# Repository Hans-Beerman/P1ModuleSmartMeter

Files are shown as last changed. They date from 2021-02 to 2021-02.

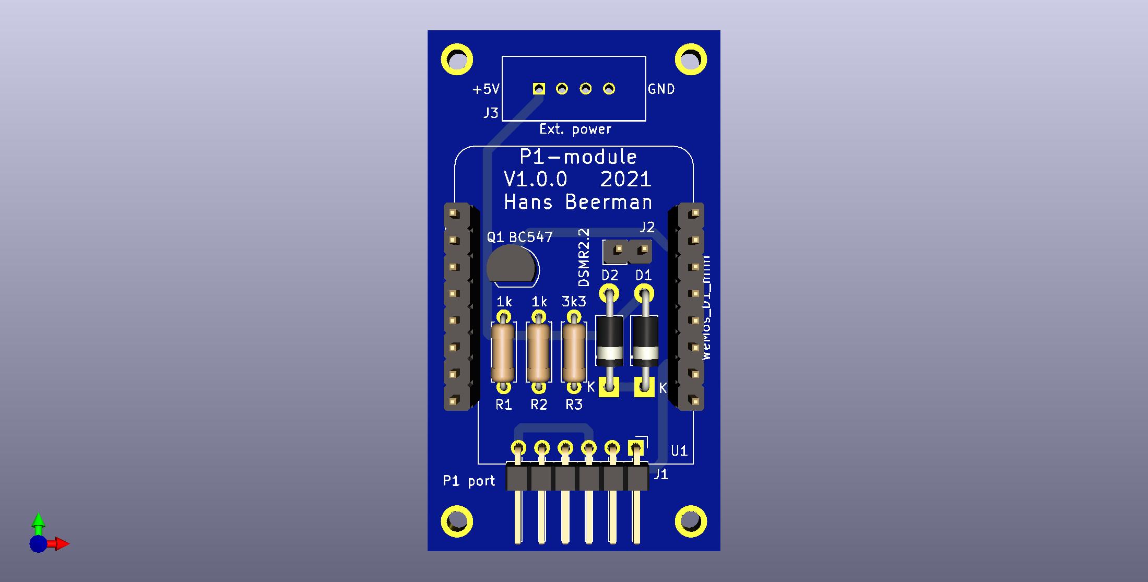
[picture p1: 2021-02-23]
KiCad_Files/WemosSmartMeter/P1-module V1.0.0.jpg

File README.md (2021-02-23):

**P1-module smart meter**

The P1-module is a small module, based on a Wemos D1 Mini (with an ESP8266) to collect information from the P1 port of a (Dutch) smart meter.

This module can be used for smart meters running DSMR Version 2.2 or higher.

For smart meters with DSMR V2.2 a jumper must be placed and the PCB must be powered by a 5V USB power supply. For more information, see the README.md in the KiCad directory of this repository

**Software for the P1-module**

The information collected from the smart meter is sent to a mqtt server of your own choice. The details about this server must be set in the .passwd.h file in the include directory of the PlatformIO project. This file must be added by yourself and should contain the following:

_/\* \*\*\*\*\*\*\*\*\*\*\*\*\*\*\*\*\*\*\*\*\*\*\*\*\*\*\*\*\*\*\*\*\*\*\*\*\*\*\*\*\*\*\*\*\*\*\*\*\*\*\*\*\*\*\*\*\*\*\*\*\*\*\*\*\*\*\*\*\*\*\*_

_PLEASE READ THIS FIRST_

_Add a file to the include directory of this project with the_

_following name:_

_.passwd.h_

_The content of this file should be:_

_#pragma once_

_// WiFi credentials_

_#define WIFI\_NETWORK &quot;YOUR\_WIFI\_NETWORK\_NAME&quot;_

_#define WIFI\_PASSWD &quot;YOUR\_WIFI\_NETWORK\_PASSWORD&quot;_

_#define FALLBACK\_WIFI\_NETWORK &quot;Dummy&quot; // or chose any other name you like_

_#define FALLBACK\_WIFI\_PASSWD &quot;12345678&quot; // or take another password_

_// mqtt server_

_#define MY\_MQTT\_HOST &quot;your\_mqtt\_host e.g. 10.10.10.10&quot;_

_#define MY\_MQTT\_PORT &quot;1883&quot;_

_#define MY\_MQTT\_USERNAME &quot;your\_mqtt\_server\_username&quot;_

_#define MY\_MQTT\_PASSWORD &quot;your\_mqtt\_server.password&quot;_

_// OTA credentials_

_#define OTA\_PASSWORD &quot;MyPassW00rd&quot; // must be the same in platformio.ini_

_Also check in the platformio.ini file the upload\_port set._

_In the current file this port is set for a serial connection to a_

_Linux Ubuntu PC for a Windows PC running Visual Studio Code with_

_PlatformIO you should use something like:_

_upload\_port = COM3_

_Or any other comport number which is used for the serial connection_

_For further information see the README.md in the repository on GitHub_

_\*\*\*\*\*\*\*\*\*\*\*\*\*\*\*\*\*\*\*\*\*\*\*\*\*\*\*\*\*\*\*\*\*\*\*\*\*\*\*\*\*\*\*\*\*\*\*\*\*\*\*\*\*\*\*\*\*\*\*\*\*\*\*\*\*\*\*\*\*\*\* \*/_

**WiFi network settings**

Default the P1-module uses the WiFi credentials as set in the .passw.h file, because in main.cpp the following #define is set:

_#define USE\_DEFAULT\_WIFI\_SETTINGS true_

If this #define is set to false:

_#define USE\_DEFAULT\_WIFI\_SETTINGS false_

In that case, if the P1-module is not able to connect to a WiFi network, the P1-module will set up a WiFi Access Point (AP) with the FALLBACK WiFi credentials as set in the .passwd.h file. Also a webserver (with IP address: 192.168.4.1) will be started.

If you connect, e.g. with a phone, a tablet or a PC to this AP, you will be able to select and configure a WiFi network and the mqtt server information, with the help of a web browser. The information set will be stored in eeprom.

**Overview of repository**

This repository has the following subdirs:

- **KiCad\_files:**

The design of the PCB used for the Node/Controller.

- **PlatformIO\_Files:**

The source code for the P1-module. For the development of this software PlatformIO is used, an Extension on Visual Studio Code.

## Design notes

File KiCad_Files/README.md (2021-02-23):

**P1-port smart meter module**

The following components are only needed if the smart meter uses DSMR version 2.2. For higher versions these components are not needed:

J3 USB connector

D1 Shottky diode

D2 Shottky diode, this diode must be replaced by a straight wire for higher DSMR versions.

J2 Jumper

In DSMR2.2 the USB connector is used to provide 5V, to be delivered by a 5V USB Power supply

For DSMR2.2 a jumper must be placed on J2, because the serial connection to the DSMR2.2 meter uses different settings. E.g. a baudrate of 9600 baud in DSMR2.2, while in highet DSMR versions the baudrate is 115200 baud.

**List of components used:**

J1 Header + cable with RJ12 connector, RJ12 naar 6 Pins Dupont-Jumper Adapter - P1 Kabel Compatible {e.g. [https://www.tinytronics.nl/shop/nl/kabels/adapters/rj12-naar-6-pins-dupont-jumper-adapter](https://www.tinytronics.nl/shop/nl/kabels/adapters/rj12-naar-6-pins-dupont-jumper-adapter))

J2 2-pole header (e.g. [https://www.tinytronics.nl/shop/nl/connectoren/pin-header/40-pins-header-male](https://www.tinytronics.nl/shop/nl/connectoren/pin-header/40-pins-header-male))

J3 USB-aansluitstekker printmontage Stekker, recht Typ A USB-stekker type A 774842 TRU COMPONENTS (e.g. [https://www.conrad.nl/p/usb-aansluitstekker-printmontage-stekker-recht-typ-a-usb-stekker-type-a-774842-tru-components-inhoud-1-stuks-1567162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](https://www.conrad.nl/p/usb-aansluitstekker-printmontage-stekker-recht-typ-a-usb-stekker-type-a-774842-tru-components-inhoud-1-stuks-1567162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))

U1 WeMos D1 Mini, Wemos D1 Mini V3 - ESP8266 - CH340 (e.g. [https://www.tinytronics.nl/shop/nl/arduino/wemos/wemos-d1-mini-v2-esp8266-12f-ch340](https://www.tinytronics.nl/shop/nl/arduino/wemos/wemos-d1-mini-v2-esp8266-12f-ch340))

Q1 BC546 (e.g. [https://www.tinytronics.nl/shop/nl/componenten/transistor-fet/npn-transistor-bc547](https://www.tinytronics.nl/shop/nl/componenten/transistor-fet/npn-transistor-bc547))

D1, D2 1N5819 (e.g. [https://www.conrad.nl/p/stmicroelectronics-skottky-diode-gelijkrichter-1n5819-do-41-40-v-enkelvoudig-155460](https://www.conrad.nl/p/stmicroelectronics-skottky-diode-gelijkrichter-1n5819-do-41-40-v-enkelvoudig-155460))

R1, R2 Resistor 1k (e.g. [https://www.conrad.nl/p/yageo-mf0207fte52-1k-metaalfilmweerstand-1-k-axiaal-bedraad-0207-06-w-1-1-stuks-1417606](https://www.conrad.nl/p/yageo-mf0207fte52-1k-metaalfilmweerstand-1-k-axiaal-bedraad-0207-06-w-1-1-stuks-1417606))

R3 Resistor 3k3 (e.g. [https://www.conrad.nl/p/yageo-mf0207fte52-3k3-metaalfilmweerstand-33-k-axiaal-bedraad-0207-06-w-1-1-stuks-1417733](https://www.conrad.nl/p/yageo-mf0207fte52-3k3-metaalfilmweerstand-33-k-axiaal-bedraad-0207-06-w-1-1-stuks-1417733))

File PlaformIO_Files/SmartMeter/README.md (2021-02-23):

**SlimmeMeter**

SlimmeMeter, de sourcecode voor een module om de slimme meter uit te lezen.

Voor het processorbordje waar deze sourcecode op draait wordt gebruik gemaakt van een Wemos D1 mini, die voorzien is van een ESP8266 processor, de robotdyn-d1-mini-pro-esp8266-4mb-cp2104

Zie bijvoorbeeld: https://www.tinytronics.nl/shop/nl/arduino/wemos/robotdyn-d1-mini-pro-esp8266-4mb-cp2104

De overige hardware is gemonteerd op een proefprintje: RobotDyn ProtoBoard Shield voor D1 Mini

Zie bijvoorbeeld: https://www.tinytronics.nl/shop/nl/arduino/wemos/robotdyn-protoboard-shield-voor-d1-mini

- **PlatformIO\_Files:**

Bevat de source code voor deze module. Voor het ontwikkelen van de software is gebruik gemaakt van PlatformIO, een extensie op Windowd Visual Studio Code. Deze subdirectory bevat alle PlatformIO project files.

Open de rootdirectory van dit project m.b.v. PlatformIO

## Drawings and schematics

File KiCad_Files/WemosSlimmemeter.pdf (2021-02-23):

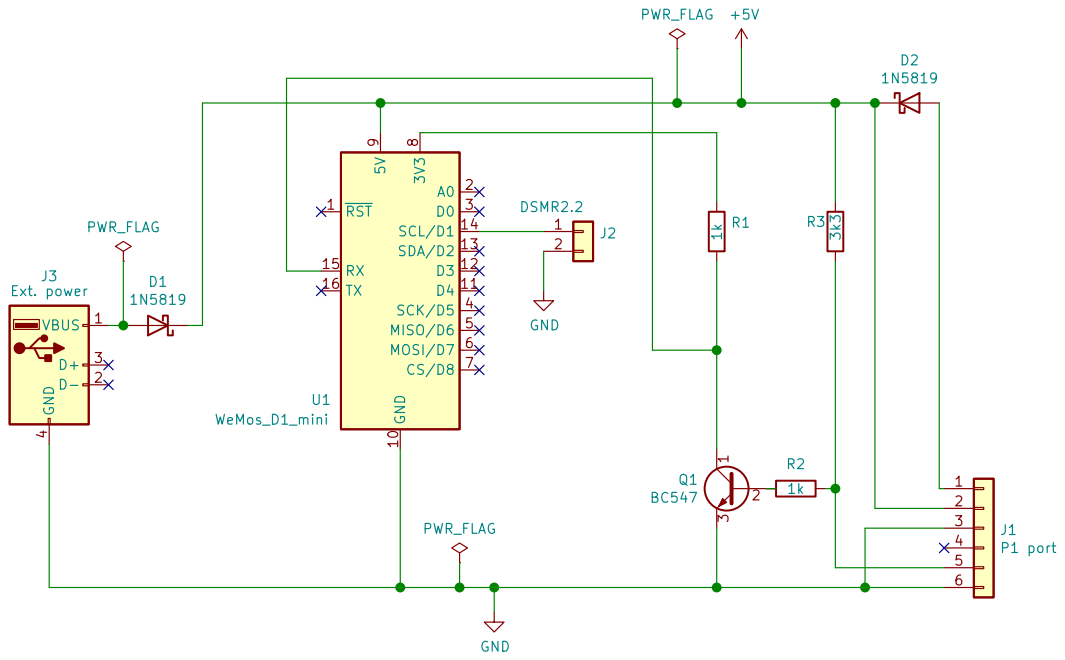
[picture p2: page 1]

Id: 1/1 Title: P1-port smart meter File: WemosSlimmemeter.sch Sheet: / SDS project Getekend door: Hans Beerman

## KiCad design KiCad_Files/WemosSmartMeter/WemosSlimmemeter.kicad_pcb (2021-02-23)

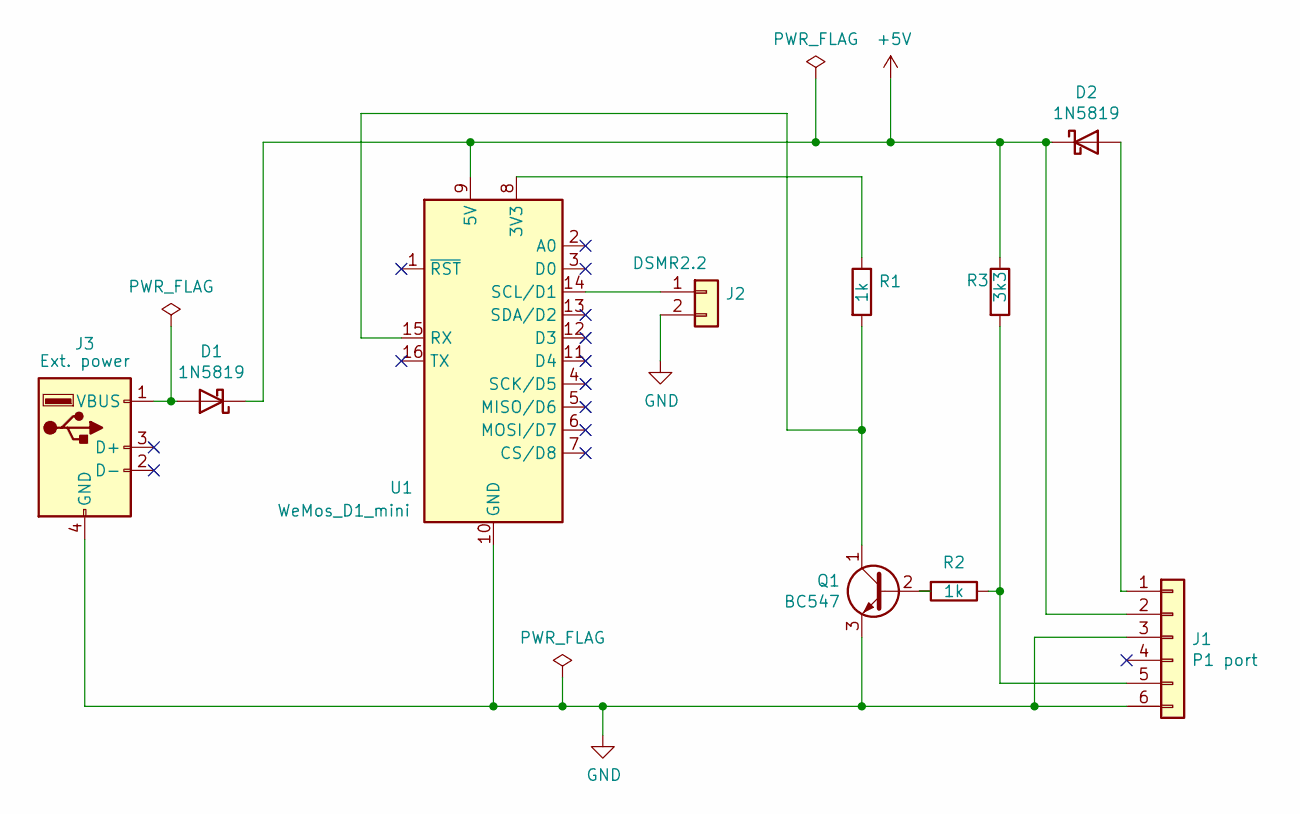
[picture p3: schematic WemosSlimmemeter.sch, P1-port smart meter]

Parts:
D1, D2: 1N5819; D_DO-41_SOD81_P10.16mm_Horizontal
J1: P1 port; PinHeader_1x06_P2.54mm_Horizontal
J2: DSMR2.2; PinHeader_1x02_P2.54mm_Vertical
J3: Ext. power; USB_A_Vertical
Q1: BC547; TO-92_Inline
R1, R2: 1k; R_Axial_DIN0207_L6.3mm_D2.5mm_P7.62mm_Horizontal
R3: 3k3; R_Axial_DIN0207_L6.3mm_D2.5mm_P7.62mm_Horizontal
U1: WeMos_D1_mini; WEMOS_D1_mini_light

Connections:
+5V: D1.1 (K), D2.1 (K), J1.2, R3.1, U1.9 (5V)
GND: J1.3, J1.6, J2.2, J3.4 (GND), Q1.3 (E), U1.10 (GND)
unnamed: D1.2 (A), J3.1 (VBUS)
unnamed: D2.2 (A), J1.1
unnamed: J1.5, R2.1, R3.2
unnamed: J2.1, U1.14 (SCL/D1)
unnamed: Q1.1 (C), R1.2, U1.15 (RX)
unnamed: Q1.2 (B), R2.2
unnamed: R1.1, U1.8 (3V3)

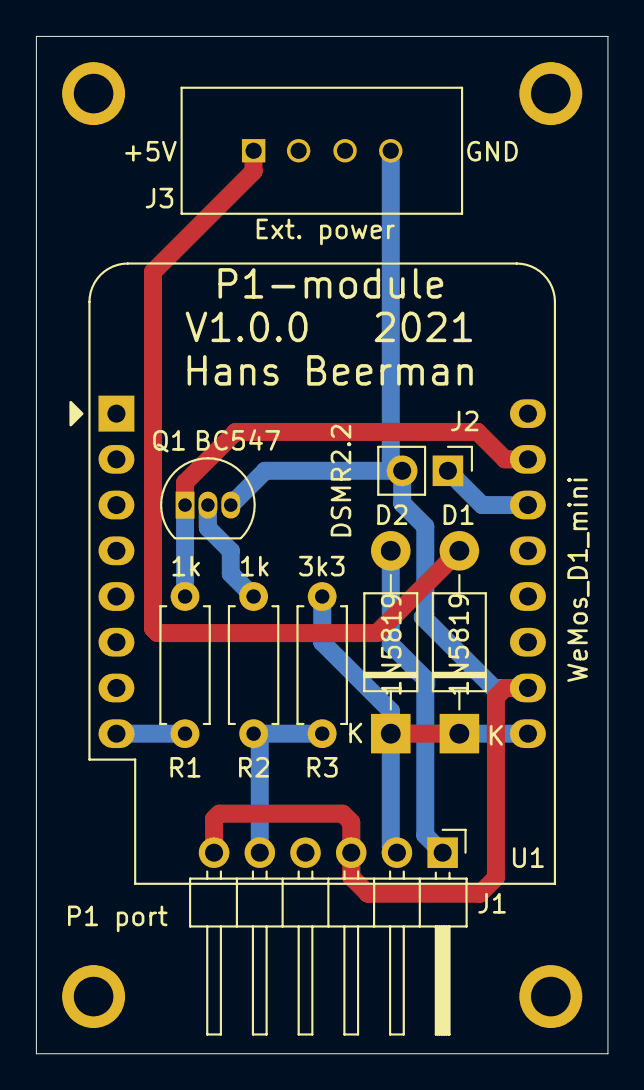
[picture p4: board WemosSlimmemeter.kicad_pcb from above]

Board: 2 copper layers, 31.8 x 56.5 mm, 10 parts (0 on the bottom side), 9 nets.

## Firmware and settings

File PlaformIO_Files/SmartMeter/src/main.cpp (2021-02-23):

#include <Arduino.h>
#include <FS.h>
#include <EEPROM.h>
#include <DNSServer.h>
#include <ESP8266WiFi.h>
#include <Ticker.h>
#include <WiFiManager.h>
#include "ESPTelnet.h" 
#include <ESP8266mDNS.h>
#include <ArduinoOTA.h>
#include <PubSubClient.h>
#include <WiFiUdp.h>
#include <NTP.h> // install NTP by Stefan Staub
//
// information about NTP.h, see: https://platformio.org/lib/show/5438/NTP
//
/*

/* ***********************************************************************
PLEASE READ THIS FIRST

Add a file to the include directory of this project with the 
following name:

.passwd.h

The content of this file should be:

#pragma once

// WiFi credentials
#define WIFI_NETWORK "YOUR_WIFI_NETWORK_NAME"
#define WIFI_PASSWD "YOUR_WIFI_NETWORK_PASSWORD"

#define FALLBACK_WIFI_NETWORK "Dummy"  // or chose any other name you like
#define FALLBACK_WIFI_PASSWD "12345678" // or take another password

// mqtt server
#define MY_MQTT_HOST "your_mqtt_host e.g. 10.10.10.10"
#define MY_MQTT_PORT "1883"
#define MY_MQTT_USERNAME "your_mqtt_server_username"
#define MY_MQTT_PASSWORD "your_mqtt_server.password"

// OTA credentials
#define OTA_PASSWORD "MyPassW00rd" // must be the same in platformio.ini

Also check in the platformio.ini file the upload_port set.

In the current file this port is set for a serial connection to a

Linux Ubuntu PC for a Windows PC running Visual Studio Code with
PlatformIO you should use something like:
upload_port = COM3
Or any other comport number which is used for the serial connection

For further information see the README.md in the repository on GitHub

*********************************************************************** */

// * Include settings
#include ".passwd.h"
#include "settingsMain.h"

// * include EEProm functions
#include "MyEEprom.h"
#define MODULE_NAME "P1PortModule"

#define USE_DEFAULT_WIFI_SETTINGS true

// * Initiate led blinker library
Ticker ticker;

// * Initiate WIFI client
WiFiClient espClient;

// WiFiClient espClient;
PubSubClient mqtt_client(espClient);

// * Initiate telnet server
ESPTelnet telnet;

// * IP address module
IPAddress ip_addr;

// * for NTP
#define NTP_UPDATE_WINDOW (1000 * 60 * 60) // in ms = 1 hour

unsigned long lastNTPUpdateTime = 0;

WiFiUDP wifiUDP;

char topic[255];
char logMess[255];
bool firstStart = true;
unsigned long measureStartTime = 0;

// To test DSMRV2.2 functionality on > DSMRV2.2 smart meter, uncomment below statement
//#define TEST_DSMRV2_2

// In case DSMR V2.2 is used
bool DSMRV2_2IsUsed = false;

bool timeStampReceived = false;

// **********************************
// * Function definitions           *
// **********************************


// **********************************
// * Ticker (System LED Blinker)    *
// **********************************

// * Blink on-board Led
void tick()
{
    // * Toggle state
    int state = digitalRead(LED_BUILTIN);    // * Get the current state of GPIO1 pin
    digitalWrite(LED_BUILTIN, !state);       // * Set pin to the opposite state
}

// **********************************
// * NTP                            *
// **********************************

NTP ntp(wifiUDP);

char ntpDateTimeStr[64];
char newDateTimeStr[64];
unsigned long NTPUpdatedTime = 0;
int currentHour;
int currentMinutes;
int currentSecs;
int currentDay;
int currentMonth;
int currentYear;

void initNTP() {
  ntp.ruleDST("CEST", Last, Sun, Mar, 2, 120); // last sunday in march 2:00, timezone +120min (+1 GMT + 1h summertime offset)
  ntp.ruleSTD("CET", Last, Sun, Oct, 3, 60); // last sunday in october 3:00, timezone +60min (+1 GMT)
  ntp.begin(false); // start NTP nonblocking
  ntp.update();

  currentHour = ntp.hours();
  currentMinutes = ntp.minutes();
  currentSecs = ntp.seconds();
  currentDay = ntp.day();
  currentMonth = ntp.month();
  currentYear = ntp.year();

  snprintf(ntpDateTimeStr, sizeof(ntpDateTimeStr), "Last boot: %4d-%02d-%02d %02d:%02d:%02d", currentYear, currentMonth, currentDay, currentHour, currentMinutes, currentSecs);

  ntp.updateInterval(NTP_UPDATE_WINDOW);
  ntp.update();
}

void getCurrentNTPTime() {
  currentHour = ntp.hours();
  currentMinutes = ntp.minutes();
  currentSecs = ntp.seconds();
  currentDay = ntp.day();
  currentMonth = ntp.month();
  currentYear = ntp.year();

  snprintf(newDateTimeStr, sizeof(newDateTimeStr), "%4d-%02d-%02d %02d:%02d:%02d", currentYear, currentMonth, currentDay, currentHour, currentMinutes, currentSecs);
}




// **********************************
// * telnet                           *
// **********************************

// Callback functions for telnet server
void onTelnetConnect(String ip) {
    Serial.print("- Telnet: ");
    Serial.print(telnet.getIP());
    Serial.println(" connected");
    telnet.println("\n\rWelcome " + telnet.getIP() + "\r");
    telnet.println("(Use ^] + q  to disconnect.)\r");
    telnet.println("\r");
    telnet.print(P1_MODULE_SOFTWARE_VERSION);
    telnet.println("\r");
    telnet.print(DATE_OFF_VERSION);
    telnet.println("\r");
    telnet.println("\r");
    telnet.println(ntpDateTimeStr);
    telnet.println("\r");
}

void onTelnetDisconnect(String ip) {
    Serial.print("- Telnet: ");
    Serial.print(ip);
    Serial.println(" disconnected");
}
void onTelnetReconnect(String ip) {
    Serial.print("- Telnet: ");
    Serial.print(ip);
    Serial.println(" reconnected");
}

void onTelnetConnectionAttempt(String ip) {
    Serial.print("- Telnet: ");
    Serial.print(telnet.getLastAttemptIP());
    Serial.println(" tried to connected");
}


void setupTelnet() {
    if (telnet.begin()) {
        telnet.onConnect(onTelnetConnect);
        telnet.onConnectionAttempt(onTelnetConnectionAttempt);
        telnet.onReconnect(onTelnetReconnect);
        telnet.onDisconnect(onTelnetDisconnect);
        Serial.println("- Telnet is running. Connect to Telnet using:");
        Serial.println("telnet " + ip_addr.toString());
    } else {
    // could not create server
        Serial.println("- Failed to create Telnet server. Is device connected to WiFi?");
        delay(10000);
        ESP.reset();
        delay(1000); 
    }
}

// **********************************
// * MQTT                           *
// **********************************

// * Send a message to a broker topic
void send_mqtt_message(const char *topic, char *payload)
{
    Serial.printf("MQTT Outgoing on %s: ", topic);
    Serial.println(payload);

    bool result = mqtt_client.publish(topic, payload, false);

    if (!result)
    {
        Serial.printf("MQTT publish to topic %s failed\n", topic);
    }
}

// * Reconnect to MQTT server and subscribe to in and out topics
bool mqtt_reconnect()
{
    // * Loop until we're reconnected
    int MQTT_RECONNECT_RETRIES = 0;

    while (!mqtt_client.connected() && MQTT_RECONNECT_RETRIES < MQTT_MAX_RECONNECT_TRIES)
    {
        MQTT_RECONNECT_RETRIES++;
        Serial.printf("MQTT connection attempt %d / %d ...\n", MQTT_RECONNECT_RETRIES, MQTT_MAX_RECONNECT_TRIES);
        snprintf(logMess, sizeof(logMess), "MQTT connection attempt %d / %d ...\n\r", MQTT_RECONNECT_RETRIES, MQTT_MAX_RECONNECT_TRIES);
        telnet.println(logMess);


        // * Attempt to connect
        if (mqtt_client.connect(HOSTNAME, MQTT_USER, MQTT_PASS))
        {
            Serial.println(F("MQTT connected!"));
            telnet.println(F("MQTT connected!\r"));

            // * Once connected, publish an announcement...
            snprintf(logMess, sizeof(logMess), "p1 port module alive, hostname: %s", HOSTNAME);
            mqtt_client.publish("Status", logMess);

            Serial.printf("MQTT root topic: %s\n", MQTT_ROOT_TOPIC);
            snprintf(logMess, sizeof(logMess), "MQTT root topic: %s\n\r", MQTT_ROOT_TOPIC);
            telnet.println(logMess);

        }
        else
        {
            Serial.print(F("MQTT Connection failed: rc="));
            Serial.println(mqtt_client.state());
            Serial.println(F(" Retrying in 2 seconds"));
            Serial.println("");
            snprintf(logMess, sizeof(logMess), "MQTT Connection failed: rc=%d\r", mqtt_client.state());
            telnet.println(logMess);
            telnet.println(F(" Retrying in 2 seconds\r"));
            telnet.println("\r");
            delay(2000);
        }
    }

    if (MQTT_RECONNECT_RETRIES >= MQTT_MAX_RECONNECT_TRIES)
    {
        Serial.printf("*** MQTT connection failed, giving up after %d tries ...\n", MQTT_RECONNECT_RETRIES);
        Serial.println(F(" Retrying in 10 seconds"));
        snprintf(logMess, sizeof(logMess), "*** MQTT connection failed, giving up after %d tries ...\n", MQTT_RECONNECT_RETRIES);
        telnet.println(logMess);
        telnet.println(F(" Retrying in 10 seconds\r"));
        return false;
    }

    return true;
}

void send_metric(const char * name, long metric)
{
    Serial.print(F("Sending metric to broker: "));
    Serial.print(name);
    Serial.print(F("="));
    Serial.println(metric);

    char output[22];
    ltoa(metric, output, 10);

    snprintf(topic, sizeof(topic), "%s/%s", MQTT_ROOT_TOPIC, name);
    send_mqtt_message(topic, output);
    yield();
}

void send_data_to_broker()
{
    send_metric("consumption_low_tarif", CONSUMPTION_LOW_TARIF);
    send_metric("consumption_high_tarif", CONSUMPTION_HIGH_TARIF);
    send_metric("delivery_low_tarif", DELIVERY_LOW_TARIF);
    send_metric("delivery_high_tarif", DELIVERY_HIGH_TARIF);
    send_metric("actual_consumption", ACTUAL_CONSUMPTION);
    send_metric("actual_delivery", ACTUAL_DELIVERY);
    send_metric("instant_power_usage", INSTANT_POWER_USAGE);
    send_metric("instant_power_current", INSTANT_POWER_CURRENT);
    send_metric("gas_meter_m3", GAS_METER_M3);

    send_metric("actual_tarif_group", ACTUAL_TARIF);
    send_metric("short_power_outages", SHORT_POWER_OUTAGES);
    send_metric("long_power_outages", LONG_POWER_OUTAGES);
    send_metric("short_power_drops", SHORT_POWER_DROPS);
    send_metric("short_power_peaks", SHORT_POWER_PEAKS);
}

// **********************************
// * P1                             *
// **********************************

unsigned int CRC16(unsigned int crc, unsigned char *buf, int len)
{
	for (int pos = 0; pos < len; pos++)
    {
		crc ^= (unsigned int)buf[pos];    // * XOR byte into least sig. byte of crc
                                          // * Loop over each bit
        for (int i = 8; i != 0; i--)
        {
            // * If the LSB is set
            if ((crc & 0x0001) != 0)
            {
                // * Shift right and XOR 0xA001
                crc >>= 1;
				crc ^= 0xA001;
			}
            // * Else LSB is not set
            else
                // * Just shift right
                crc >>= 1;
		}
	}
	return crc;
}

bool isNumber(char *res, int len)
{
    for (int i = 0; i < len; i++)
    {
        if (((res[i] < '0') || (res[i] > '9')) && (res[i] != '.' && res[i] != 0))
            return false;
    }
    return true;
}

int FindCharInArrayRev(char array[], char c, int len)
{
    for (int i = len - 1; i >= 0; i--)
    {
        if (array[i] == c)
            return i;
    }
    return -1;
}

long getValue(char *buffer, int maxlen, char startchar, char endchar)
{
    int s = FindCharInArrayRev(buffer, startchar, maxlen - 2);
    int l = FindCharInArrayRev(buffer, endchar, maxlen - 2) - s - 1;

    char res[16];
    memset(res, 0, sizeof(res));

    if (strncpy(res, buffer + s + 1, l))
    {
        if (endchar == '*')
        {
            if (isNumber(res, l))
                // * Lazy convert float to long
                return (1000 * atof(res));
        }
        else if (endchar == ')')
        {
            if (isNumber(res, l))
                return atof(res);
        }
    }
    return 0;
}

void getDateTimeP1(char *buffer, int maxlen, char startchar, char endchar)
{
    char tmpStr[10];
    int s = FindCharInArrayRev(buffer, startchar, maxlen);
    int l = FindCharInArrayRev(buffer, endchar, maxlen) - s - 1;
    
    memset(DATE_TIME_P1, 0, sizeof(DATE_TIME_P1));

    if (strncpy(DATE_TIME_P1, buffer + s + 1, l))
    {
        DATE_TIME_P1[l] = 0;
        if (l == 13) {
            tmpStr[0] = DATE_TIME_P1[6];
            tmpStr[1] = DATE_TIME_P1[7];
            tmpStr[2] = 0;
            P1_HOURS = atoi(tmpStr);
            tmpStr[0] = DATE_TIME_P1[8];
            tmpStr[1] = DATE_TIME_P1[9];
            tmpStr[2] = 0;
            P1_MINUTES = atoi(tmpStr);
        }
    } else {
        DATE_TIME_P1[0] = 0;
        P1_HOURS = -1;
        P1_MINUTES = -1;
    }
}

void getDateTimeNTP(void) {
    int year = ntp.year();
    int month = ntp.month();
    int day = ntp.day();
    int seconds = ntp.seconds();
    
    year = year - 2000;
    P1_HOURS = ntp.hours();
    P1_MINUTES = ntp.minutes();
    if (ntp.isDST() == 0) {
        snprintf(DATE_TIME_P1, sizeof(DATE_TIME_P1), "%02d%02d%02d%02d%02d%02d%c", year, month, day, P1_HOURS, P1_MINUTES, seconds, 'W');
    } else {
        snprintf(DATE_TIME_P1, sizeof(DATE_TIME_P1), "%02d%02d%02d%02d%02d%02d%c", year, month, day, P1_HOURS, P1_MINUTES, seconds, 'S');
    }
#ifdef TEST_DSMRV2_2    
    telnet.println(DATE_TIME_P1);
#endif    
}

bool decode_telegram(int len)
{
    int startChar = FindCharInArrayRev(telegram, '/', len);
    int endChar = FindCharInArrayRev(telegram, '!', len);
    bool validCRCFound = false;
    bool messageComplete = false;
    int cnt;

    for (cnt = 0; cnt < len; cnt++) {
        Serial.print(telegram[cnt]);
#ifdef DEBUGIT        
        logMess[cnt] = telegram[cnt];
#endif        
    }
    Serial.println("\r");
#ifdef DEBUGIT        
    logMess[cnt] = 0;
    telnet.println(logMess);
#endif    
    if (DSMRV2_2IsUsed) {
        if (endChar >= 0) {
            messageComplete = true;
            // In DSMRV2.2 no timestamp is given, but check anyhow
            if (!timeStampReceived) {
                // use NTP time instead
                getDateTimeNTP();
            }
        }
    } else {

        if (startChar >= 0) {
            // * Start found. Reset CRC calculation
            currentCRC = CRC16(0x0000, (unsigned char *)telegram + startChar, len - startChar);
        } else if (endChar >= 0) {
            // In DSMR V4 and higher normaly a timestamp is given, but for test purposes it is not used
            if (!timeStampReceived) {
                // use NTP time instead
                getDateTimeNTP();
            }

            // * Add to crc calc
            currentCRC = CRC16(currentCRC, (unsigned char*)telegram + endChar, 1);

            char messageCRC[5];
            strncpy(messageCRC, telegram + endChar + 1, 4);

            messageCRC[4] = 0;   // * Thanks to HarmOtten (issue 5)
            validCRCFound = (strtol(messageCRC, NULL, 16) == currentCRC);

            if (validCRCFound) {
                Serial.println(F("CRC Valid!\r"));
                VALID_MESSAGES++;
#ifdef DEBUGIT        
                telnet.println(F("CRC Valid!\r"));
#endif            
                messageComplete = true;
            } else {
                Serial.println(F("CRC Invalid!\r"));
                INVALID_MESSAGES++;
                snprintf(logMess, sizeof(logMess), "CRC Invalid! [total = %d]\r", INVALID_MESSAGES);
                telnet.println(logMess);
                messageComplete = false;
            }

            currentCRC = 0;
        } else {
            currentCRC = CRC16(currentCRC, (unsigned char*) telegram, len);
        }
    }

    // 0-0:1.0.0.255(201113173500W)
    // 0-0:1.0.0.255 = Date - time stamp P1 message
    if (strncmp(telegram, "0-0:1.0.0", strlen("0-0:1.0.0")) == 0) {
        timeStampReceived = true;
#ifdef TEST_DSMRV2_2
        timeStampReceived = false;
        return messageComplete;
#endif        
        // get DATE_TIME_P1
        getDateTimeP1(telegram, len, '(', ')');
        return messageComplete;
    }

    // 1-0:1.8.1(000992.992*kWh)
    // 1-0:1.8.1 = Elektra verbruik laag tarief (DSMR v5.0.2)
    if (strncmp(telegram, "1-0:1.8.1", strlen("1-0:1.8.1")) == 0) {
        CONSUMPTION_LOW_TARIF = getValue(telegram, len, '(', '*');
        return messageComplete;
    }

    // 1-0:1.8.2(000560.157*kWh)
    // 1-0:1.8.2 = Elektra verbruik hoog tarief (DSMR v5.0.2)
    if (strncmp(telegram, "1-0:1.8.2", strlen("1-0:1.8.2")) == 0) {
        CONSUMPTION_HIGH_TARIF = getValue(telegram, len, '(', '*');
        return messageComplete;
    }

    // 1-0:2.8.1(000000.000*kWh)
    // 1-0:2.8.1 = Elektra levering laag tarief (DSMR v5.0.2)
    if (strncmp(telegram, "1-0:2.8.1", strlen("1-0:2.8.1")) == 0) {
        DELIVERY_LOW_TARIF = getValue(telegram, len, '(', '*');
        return messageComplete;
    }

    // 1-0:2.8.2(000000.000*kWh)
    // 1-0:2.8.2 = Elektra levering hoog tarief (DSMR v5.0.2)
    if (strncmp(telegram, "1-0:2.8.2", strlen("1-0:2.8.2")) == 0) {
        DELIVERY_HIGH_TARIF = getValue(telegram, len, '(', '*');
        return messageComplete;
    }

    // 1-0:1.7.0(00.000*kW) Actueel verbruik
    // 1-0:1.7.0 = Electricity consumption actual usage (DSMR v5.0.2)
    if (strncmp(telegram, "1-0:1.7.0", strlen("1-0:1.7.0")) == 0) {
        ACTUAL_CONSUMPTION = getValue(telegram, len, '(', '*');
        if (ACTUAL_CONSUMPTION > PEAK_CONSUMPTION) {
            PEAK_CONSUMPTION = ACTUAL_CONSUMPTION;
        }
        return messageComplete;
    }

    // 1-0:2.7.0(00.000*kW) Actuele teruglevering
    // 1-0:2.7.0 = Electricity consumption actual delivery (DSMR v5.0.2)
    if (strncmp(telegram, "1-0:2.7.0", strlen("1-0:2.7.0")) == 0) {
        ACTUAL_DELIVERY = getValue(telegram, len, '(', '*');
        if (ACTUAL_DELIVERY > PEAK_DELIVERY) {
            PEAK_DELIVERY = ACTUAL_DELIVERY;
        }
        return messageComplete;
    }

    // 1-0:21.7.0(00.378*kW)
    // 1-0:21.7.0 = Instantaan vermogen Elektriciteit levering
    if (strncmp(telegram, "1-0:21.7.0", strlen("1-0:21.7.0")) == 0) {
        INSTANT_POWER_USAGE = getValue(telegram, len, '(', '*');
        return messageComplete;
    }

    // 1-0:31.7.0(002*A)
    // 1-0:31.7.0 = Instantane stroom Elektriciteit
    if (strncmp(telegram, "1-0:31.7.0", strlen("1-0:31.7.0")) == 0) {
        INSTANT_POWER_CURRENT = getValue(telegram, len, '(', '*');
        return messageComplete;
    }

    // 0-1:24.2.1(150531200000S)(00811.923*m3)
    // 0-1:24.2.1 = Gas (DSMR v5.0.2)
    if (strncmp(telegram, "0-1:24.2.1", strlen("0-1:24.2.1")) == 0) {
        GAS_METER_M3 = getValue(telegram, len, '(', '*');
        return messageComplete;
    }

    // 0-0:96.14.0(0001)
    // 0-0:96.14.0 = Actual Tarif
    if (strncmp(telegram, "0-0:96.14.0", strlen("0-0:96.14.0")) == 0) {
        ACTUAL_TARIF = getValue(telegram, len, '(', ')');
        return messageComplete;
    }

    // 0-0:96.7.21(00003)
    // 0-0:96.7.21 = Aantal onderbrekingen Elektriciteit
    if (strncmp(telegram, "0-0:96.7.21", strlen("0-0:96.7.21")) == 0) {
        SHORT_POWER_OUTAGES = getValue(telegram, len, '(', ')');
        return messageComplete;
    }

    // 0-0:96.7.9(00001)
    // 0-0:96.7.9 = Aantal lange onderbrekingen Elektriciteit
    if (strncmp(telegram, "0-0:96.7.9", strlen("0-0:96.7.9")) == 0) {
        LONG_POWER_OUTAGES = getValue(telegram, len, '(', ')');
        return messageComplete;
    }

    // 1-0:32.32.0(00000)
    // 1-0:32.32.0 = Aantal korte spanningsdalingen Elektriciteit in fase 1
    if (strncmp(telegram, "1-0:32.32.0", strlen("1-0:32.32.0")) == 0) {
        SHORT_POWER_DROPS = getValue(telegram, len, '(', ')');
        return messageComplete;
    }

    // 1-0:32.36.0(00000)
    // 1-0:32.36.0 = Aantal korte spanningsstijgingen Elektriciteit in fase 1
    if (strncmp(telegram, "1-0:32.36.0", strlen("1-0:32.36.0")) == 0) {
        SHORT_POWER_PEAKS = getValue(telegram, len, '(', ')');
        return messageComplete;
    }

    // 1-0:21.7.0(00.000*kW)
    // 1-0:21.7.0 = Actuele verbruik L1
    if (strncmp(telegram, "1-0:21.7.0", strlen("1-0:21.7.0")) == 0) {
        L1_DETECTED = true;
        INSTANT_ACTIVE_POWER_CONSUMPTION_L1 = getValue(telegram, len, '(', '*');
        return messageComplete;
    }

    // 1-0:41.7.0(00.000*kW)
    // 1-0:41.7.0 = Actuele verbruik L2
    if (strncmp(telegram, "1-0:41.7.0", strlen("1-0:41.7.0")) == 0) {
        L2_DETECTED = true;
        INSTANT_ACTIVE_POWER_CONSUMPTION_L2 = getValue(telegram, len, '(', '*');
        return messageComplete;
    }

    // 1-0:61.7.0(00.000*kW)
    // 1-0:61.7.0 = Actuele verbruik L3
    if (strncmp(telegram, "1-0:61.7.0", strlen("1-0:61.7.0")) == 0) {
        L3_DETECTED = true;
        INSTANT_ACTIVE_POWER_CONSUMPTION_L3 = getValue(telegram, len, '(', '*');
        return messageComplete;
    }

    // 1-0:22.7.0(00.000*kW)
    // 1-0:22.7.0 = Actuele opbrengst L1
    if (strncmp(telegram, "1-0:22.7.0", strlen("1-0:22.7.0")) == 0) {
        L1_DETECTED = true;
        INSTANT_ACTIVE_POWER_DELIVERY_L1 = getValue(telegram, len, '(', '*');
        return messageComplete;
    }
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
void loop()
{
    read_p1_serial();

    ArduinoOTA.handle();

    telnet.loop();

    ntpUpdateLoop();

    if (!mqtt_client.connected()) {
        now = millis();

        if (((now - LAST_RECONNECT_ATTEMPT) > 30000) || MQTTFirstTime) {
            MQTTFirstTime = false;
            LAST_RECONNECT_ATTEMPT = now;
            Serial.println("mqtt client not connected\r");
            telnet.println("mqtt client not connected\r");

            if (mqtt_reconnect())
            {
                MQTTFirstTime = true;
            }
        }
    } else {
        if (firstTime) {
            Serial.println("First time = true \r");
            firstTime = false;
            snprintf(logMess, sizeof(logMess), "p1 port module alive, hostname: %s", HOSTNAME);
            mqtt_client.publish("Status", logMess);
            telnet.print(logMess);
            telnet.print("\n\r");
        }
    }
    mqtt_client.loop();
}

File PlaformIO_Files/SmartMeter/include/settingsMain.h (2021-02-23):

/*
      Copyright 2020      Hans Beerman <hans.beerman@xs4all.nl>
                          
   Licensed under the Apache License, Version 2.0 (the "License");
   you may not use this file except in compliance with the License.
   You may obtain a copy of the License at

       http://www.apache.org/licenses/LICENSE-2.0

   Unless required by applicable law or agreed to in writing, software
   distributed under the License is distributed on an "AS IS" BASIS,
   WITHOUT WARRANTIES OR CONDITIONS OF ANY KIND, either express or implied.
   See the License for the specific language governing permissions and
   limitations under the License.
*/

#pragma once

// software version
#define P1_MODULE_SOFTWARE_VERSION "P1 Port Smart Meter Version 1.0.0.0  Copyright Hans Beerman [2020 - 2021]"
#define DATE_OFF_VERSION "Date: 2021-02-23\n\r"

// * Baud rate for both hardware and software serial
//#define BAUD_RATE 115200 // baudrate for DSMR > V2.2
#define BAUD_RATE 115200 // baudrate for DSMR > V2.2
// settings for DSMR V2.2
#define BAUD_RATE_DSMR_2_2 9600
#define SERIAL_PORT_SETTINGS_DSMR_2_2 SERIAL_7E1

// * P1 Meter RX pin
//#define P1_SERIAL_RX D2

// DSMR version jumper. If jumper is installed, serial port settings are 9600 baud 7 bits even parity 1 stopbit
// if not serial port settings are 115200 baud 8 bits no parity 1 stopbit
#define PIN_DSMR_V2_2 D1

// * Max telegram length
#define P1_MAXLINELENGTH 128

// * The hostname of our little creature
#define HOSTNAME "p1-port-smart-meter"

// * Wifi timeout in milliseconds
#define WIFI_TIMEOUT 30000
// * WiFiManager timeout in seconds
#define WIFI_MANAGER_TIMEOUT 120 // 2 minutes

// * MQTT network settings
#define MQTT_MAX_RECONNECT_TRIES 10

// * MQTT root topic
#define MQTT_ROOT_TOPIC "sensors/power/p1meter"

// * MQTT Last reconnection counter
unsigned long LAST_RECONNECT_ATTEMPT = 0;

// * To be filled with EEPROM data

//char MQTT_HOST[64] = "10.0.0.132";
char MQTT_HOST[64] = MY_MQTT_HOST;
char MQTT_PORT[6]  = MY_MQTT_PORT;
char MQTT_USER[32] = MY_MQTT_USERNAME;
char MQTT_PASS[32] = MY_MQTT_PASSWORD;

// * Set to store received telegram
char telegram[P1_MAXLINELENGTH + 2];

// * set if P1 message is completely decoded
// bool P1_Message_Is_Decoded = false;
// bool previous_P1_Message_Is_Decoded = false;

// Valid/invalid messages count
int VALID_MESSAGES = 0;
int INVALID_MESSAGES = 0;

// * Set to store date - time value P1 message
char DATE_TIME_P1[15];
int P1_HOURS = -1;
int P1_MINUTES = -1;
char PREVIOUS_DATE_TIME_P1[15];
int PREVIOUS_P1_HOURS = -1;
int PREVIOUS_P1_MINUTES = -1;

// * Set to store the data values read
long CONSUMPTION_LOW_TARIF;
long CONSUMPTION_HIGH_TARIF;
long DELIVERY_LOW_TARIF;
long DELIVERY_HIGH_TARIF;
long ACTUAL_CONSUMPTION;
long ACTUAL_DELIVERY;
long INSTANT_POWER_CURRENT;
long INSTANT_POWER_USAGE;
long INSTANT_ACTIVE_POWER_CONSUMPTION_L1 = 0;
long INSTANT_ACTIVE_POWER_CONSUMPTION_L2 = 0;
long INSTANT_ACTIVE_POWER_CONSUMPTION_L3 = 0;
long INSTANT_ACTIVE_POWER_DELIVERY_L1 = 0;
long INSTANT_ACTIVE_POWER_DELIVERY_L2 = 0;
long INSTANT_ACTIVE_POWER_DELIVERY_L3 = 0;
long SUM_INSTANT_ACTIVE_POWER_CONSUMPTION_L1 = 0;
long SUM_INSTANT_ACTIVE_POWER_CONSUMPTION_L2 = 0;
long SUM_INSTANT_ACTIVE_POWER_CONSUMPTION_L3 = 0;
long SUM_INSTANT_ACTIVE_POWER_DELIVERY_L1 = 0;
long SUM_INSTANT_ACTIVE_POWER_DELIVERY_L2 = 0;
long SUM_INSTANT_ACTIVE_POWER_DELIVERY_L3 = 0;

long GAS_METER_M3;
bool L1_DETECTED = false;
bool L2_DETECTED = false;
bool L3_DETECTED = false;

long PEAK_CONSUMPTION = 0;
long PEAK_DELIVERY = 0;

long PREVIOUS_CONSUMPTION_LOW_TARIF;
long PREVIOUS_CONSUMPTION_HIGH_TARIF;
long PREVIOUS_DELIVERY_LOW_TARIF;
long PREVIOUS_DELIVERY_HIGH_TARIF;
long PREVIOUS_ACTUAL_CONSUMPTION;
long PREVIOUS_ACTUAL_DELIVERY;
long PREVIOUS_INSTANT_POWER_CURRENT;
long PREVIOUS_INSTANT_POWER_USAGE;
long PREVIOUS_GAS_METER_M3;

// Set to store data counters read
long ACTUAL_TARIF;
long SHORT_POWER_OUTAGES;
long LONG_POWER_OUTAGES;
long SHORT_POWER_DROPS;
long SHORT_POWER_PEAKS;

long PREVIOUS_ACTUAL_TARIF;
long PREVIOUS_SHORT_POWER_OUTAGES;
long PREVIOUS_LONG_POWER_OUTAGES;
long PREVIOUS_SHORT_POWER_DROPS;
long PREVIOUS_SHORT_POWER_PEAKS;


// * Set during CRC checking
int currentCRC = 0;
